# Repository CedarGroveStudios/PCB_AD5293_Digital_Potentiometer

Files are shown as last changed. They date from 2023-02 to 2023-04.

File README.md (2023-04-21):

# PCB_AD5293_Digital_Potentiometer
### _A small breakout board for the 100K AD5293 digital potentiometer._

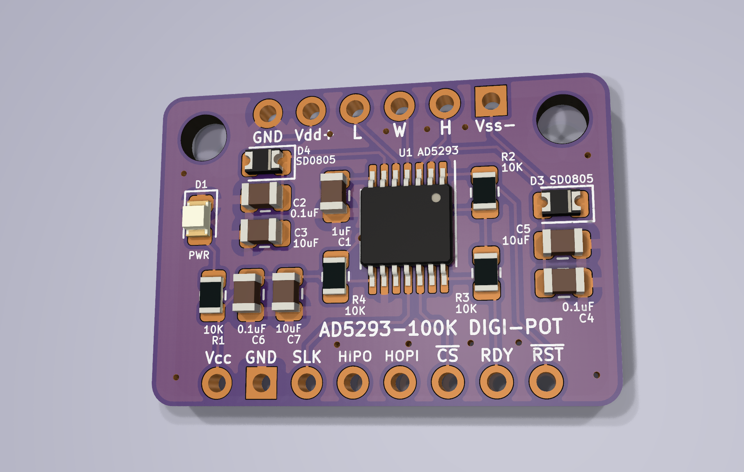
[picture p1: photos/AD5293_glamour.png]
Image During Initial Test


The AD5293 Digital Potentiometer is an SPI, 100K-ohm device. The potentiometer sports 1024 resistance steps. The digital logic power requires 2.7v to 5.5v. The potentiometer circuit operates with dual analog supply voltages from +/-9v to +/-16.5v. The pins act similarly to a passive resistive potentiometer, but require that voltages placed on any of the three pins not exceed the analog power supply voltages.

The Cedar Grove AD5293 custom breakout board provides power and signal connections for SPI and the potentiometer chip. The AD5293 is also used in the AD9833-based Cedar Grove Precision VCO Eurorack module.

A CircuitPython library is available: https://github.com/CedarGroveStudios/CircuitPython_AD5293



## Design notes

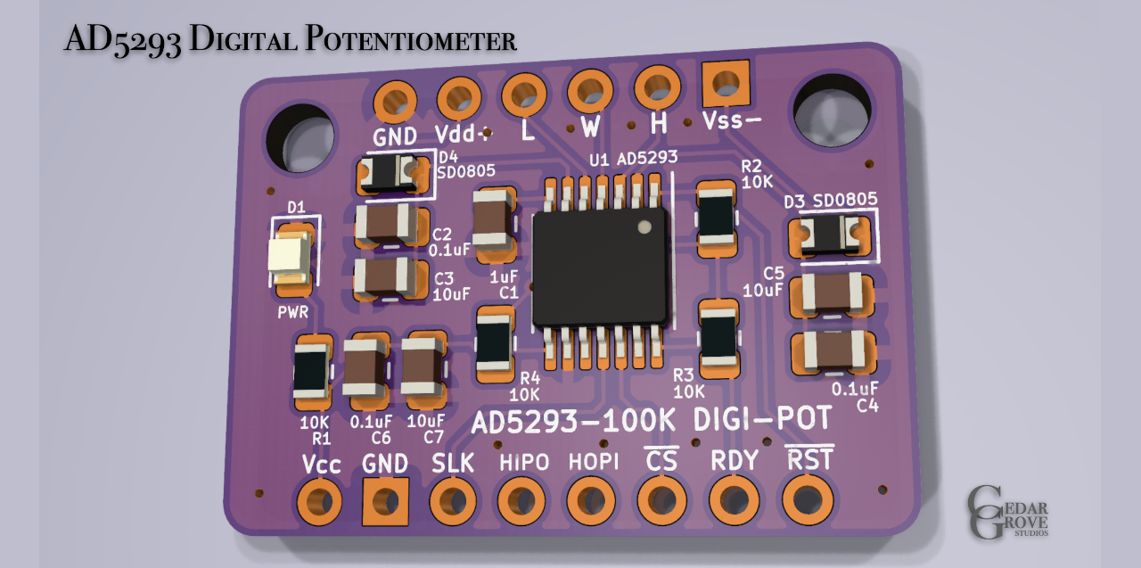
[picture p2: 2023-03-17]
photos/AD5293_social.png

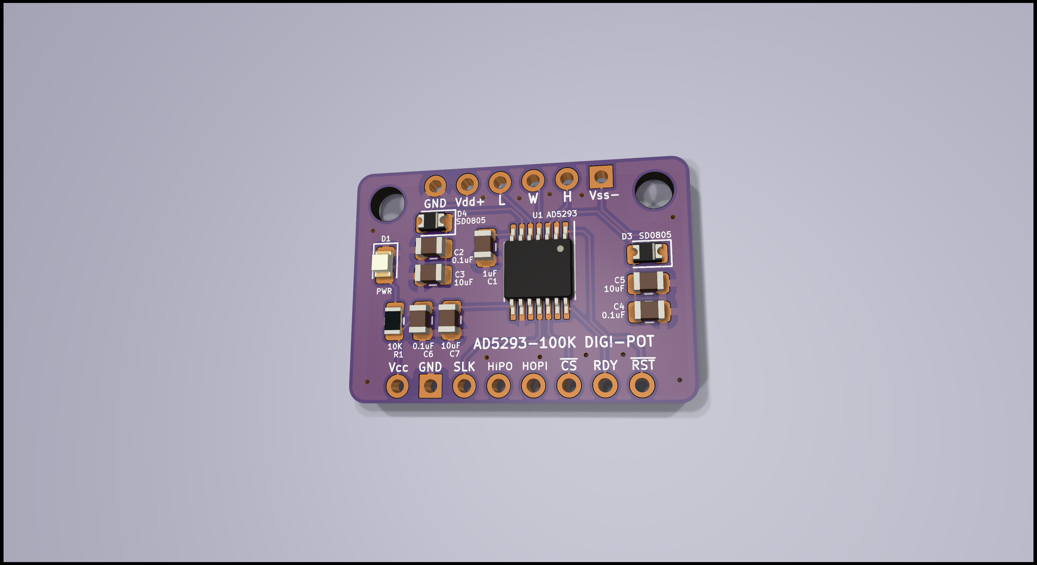
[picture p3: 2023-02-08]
PCB/breakout_glamour.png

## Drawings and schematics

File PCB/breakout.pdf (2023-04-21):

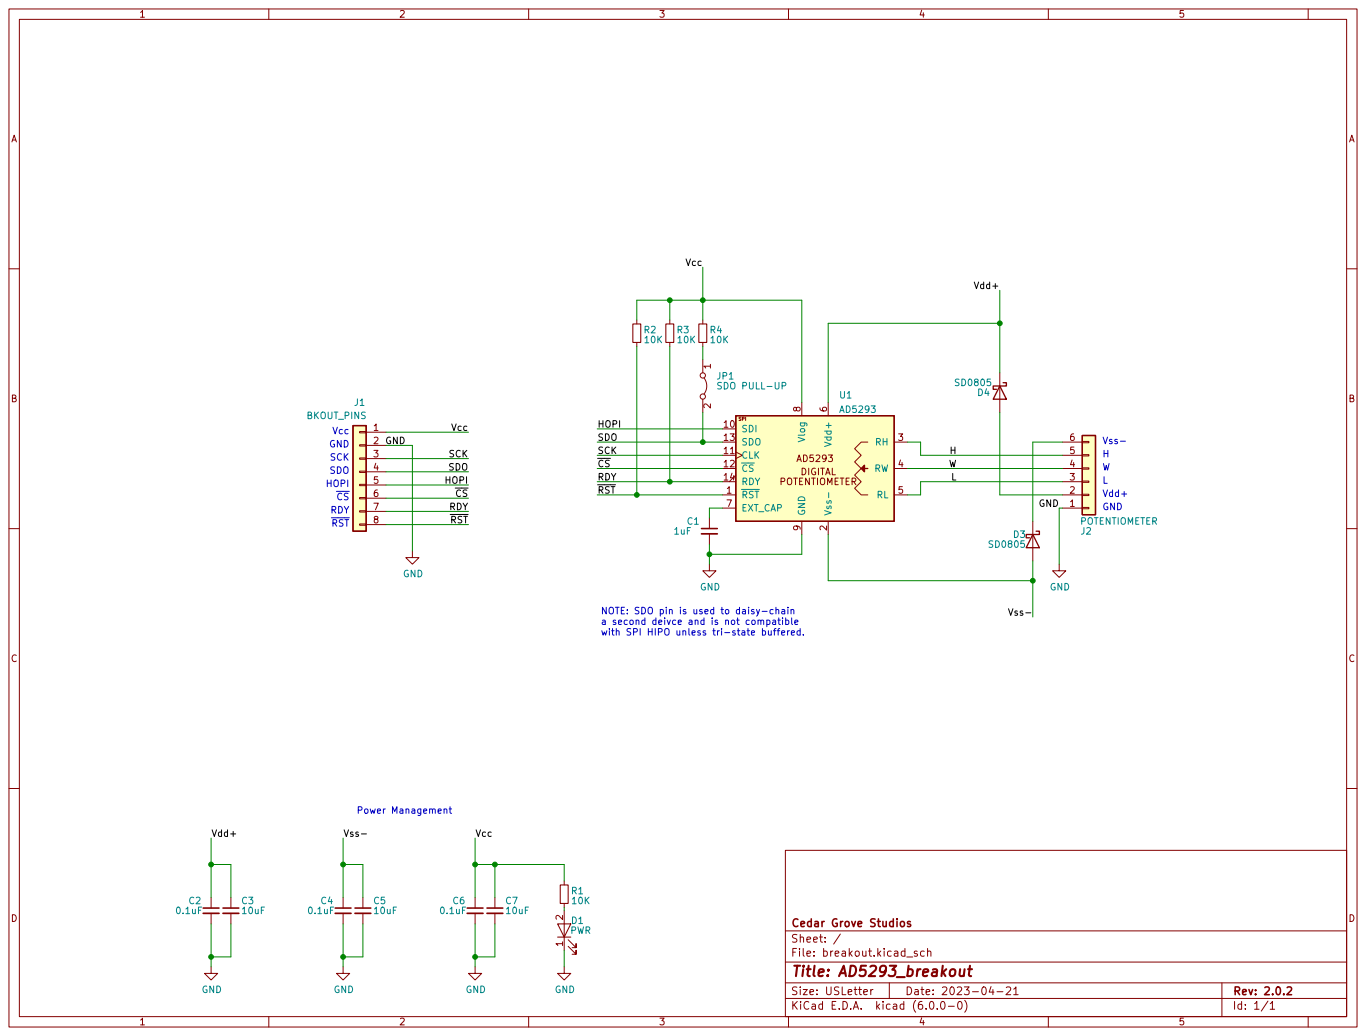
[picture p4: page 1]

NOTE: SDO pin is used to daisy-chain

File: breakout.kicad_sch Sheet: / Cedar Grove Studios GND

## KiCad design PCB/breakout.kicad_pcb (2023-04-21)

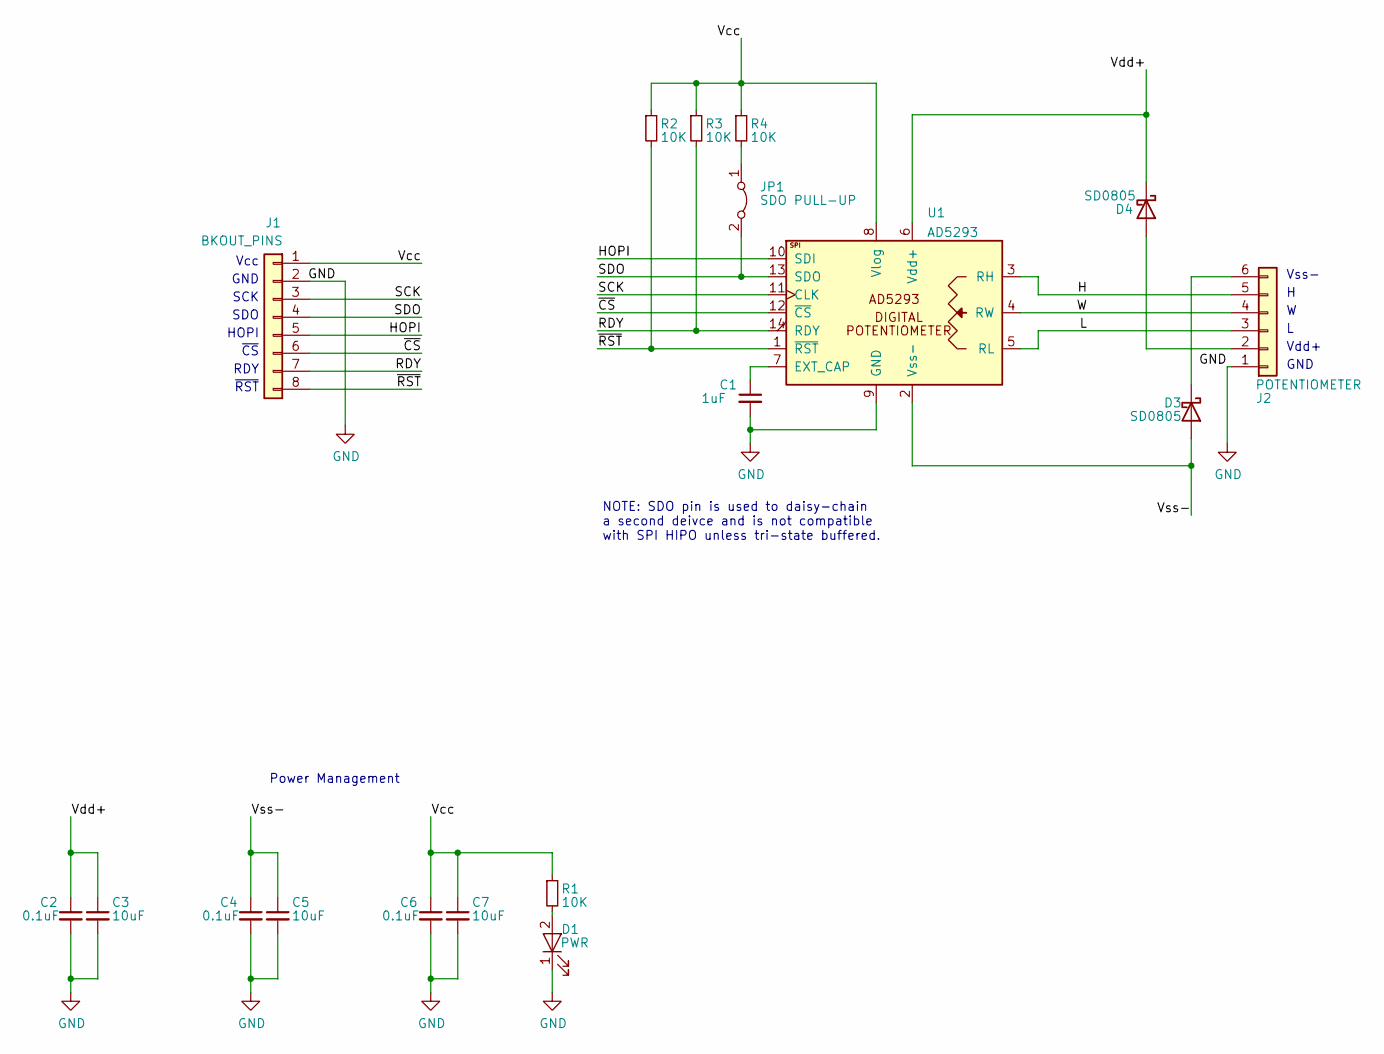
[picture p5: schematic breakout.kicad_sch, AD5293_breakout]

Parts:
C1: 1uF; C_0805_2012Metric
C2, C4, C6: 0.1uF; C_0805_2012Metric
C3, C5, C7: 10uF; C_0805_2012Metric
D1: PWR; LED_0805_2012Metric
D3, D4: SD0805; D_0805_2012Metric
J1: BKOUT_PINS; PinSocket_1x08_P2.54mm_Vertical
J2: POTENTIOMETER; PinSocket_1x06_P2.54mm_Vertical
JP1: SDO PULL-UP; SolderJumper-2_P1.3mm_Bridged_RoundedPad1.0x1.5mm
R1, R2, R3, R4: 10K; R_0805_2012Metric
U1: AD5293; TSSOP-14_4.4x5mm_P0.65mm

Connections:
/H: J2.5, U1.3 (RH)
/HOPI: J1.5, U1.10 (SDI)
/L: J2.3, U1.5 (RL)
/RDY: J1.7, R3.2, U1.14 (RDY)
/SCK: J1.3, U1.11 (CLK)
/SDO: J1.4, JP1.2 (B), U1.13 (SDO)
/Vcc: C6.1, C7.1, J1.1, R1.1, R2.1, R3.1, R4.1, U1.8 (Vlog)
/Vdd+: C2.1, C3.1, D4.1 (K), U1.6 (Vdd+)
/Vss-: C4.1, C5.1, D3.2 (A), U1.2 (Vss-)
/W: J2.4, U1.4 (RW)
/~CS: J1.6, U1.12 (~CS)
/~RST: J1.8, R2.2, U1.1 (~RST)
GND: C1.2, C2.2, C3.2, C4.2, C5.2, C6.2, C7.2, D1.1 (K), J1.2, J2.1, U1.9 (GND)
unnamed: C1.1, U1.7 (EXT_CAP)
unnamed: D1.2 (A), R1.2
unnamed: D3.1 (K), J2.6
unnamed: D4.2 (A), J2.2
unnamed: JP1.1 (A), R4.2

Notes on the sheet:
Vss-
Vcc
RDY
SCK
~{CS}
Vdd+
GND
Power Management
HOPI
~{RST}
SDO
NOTE: SDO pin is used to daisy-chain a second deivce and is not compatible with SPI HIPO unless tri-state buffered.

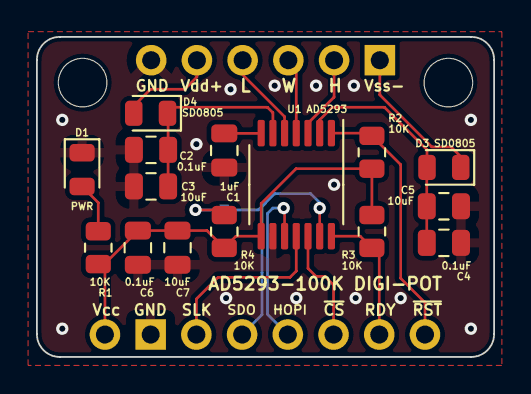
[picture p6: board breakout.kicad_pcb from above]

Board: 2 copper layers, 25.4 x 17.8 mm, 18 parts (1 on the bottom side), 18 nets.

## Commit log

2023-02-05 initial repo load
    [AD5245_breakout-B.Cu.gbl, AD5245_breakout-B.Mask.gbs, AD5245_breakout-B.SilkS.gbo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]
2023-02-05 create gerbers
    [AD5245_breakout-B.Cu.gbl, AD5245_breakout-B.Mask.gbs, AD5245_breakout-B.SilkS.gbo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]
2023-02-05 rev 0.0.0 final
    [breakout-B_Cu.gbl, breakout-B_Mask.gbs, breakout-B_Silkscreen.gbo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]
2023-02-05 update gerbers
2023-02-06 add mounting holes
    [breakout.kicad_pcb, breakout.kicad_sch]
2023-02-06 add mounting holes; version 1.0.0
    [breakout-B_Cu.gbl, breakout-B_Mask.gbs, breakout-B_Silkscreen.gbo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]
2023-02-08 refactor layout design; simplify routing
    [breakout-B_Cu.gbl, breakout-B_Mask.gbs, breakout-B_Silkscreen.gbo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]
2023-02-08 update gerbers and backups
2023-03-17 update to ver 2.0.0
    [breakout-B_Cu.gbl, breakout-B_Mask.gbs, breakout-B_Silkscreen.gbo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]
2023-03-19 kicad backup
2023-03-26 update PCB design
    [breakout-B_Cu.gbl, breakout-B_Mask.gbs, breakout-B_Silkscreen.gbo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]
2023-03-27 update kicad backup
2023-04-21 update design; add SDO pull-up jumper
    [breakout-B_Cu.gbl, breakout-B_Mask.gbs, breakout-B_Silkscreen.gbo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]
2023-04-21 update kicad backups
2023-04-21 update jumper solder mask
    [breakout-B_Cu.gbl, breakout-B_Mask.gbs, breakout-B_Silkscreen.gbo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]
